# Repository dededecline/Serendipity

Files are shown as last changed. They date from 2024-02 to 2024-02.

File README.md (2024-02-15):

# Serendipity
Serendipity in silver top with "brass" DDD logo badge color. Keycap set is JTK Grìseann, a WoB set with green US-International sublegends. Background is a series of interlocking swirls and circles in dark blue, light blue, teal, and white with yellow "flower" symbols.

## Board Details
Serendipity is a collaboration between [dededecline](https://github.com/dededecline) and [liv](https://github.com/ojthetiny)

Photos by group buy participants can be found [here!](https://imgur.com/a/I6LpYkj)

More info can be found on the [Geekhack interest check.](https://geekhack.org/index.php?topic=119558)

## Hardware
* **Back Case Screws:** [4x m3x14mm](https://www.mcmaster.com/92832A566)
* **Front Case Screws:** [4x m3x8mm](https://www.mcmaster.com/90991A113)
* **Weight Screws:** [2x m3x5mm countersunk](https://www.mcmaster.com/90236A118)
* **Plate Screws:** [8x m3x8mm](https://www.mcmaster.com/90991A113)
* **Badge Screws:** [2x m2x5mm](https://www.mcmaster.com/90236A103)
* **DB Screws:** [4x m2x5mm](https://www.mcmaster.com/90236A103)
* **O-Rings:** [16x 1.5mmx2.5mm, 70 duro recommended](https://www.theoringstore.com/store/index.php?main_page=product_info&products_id=1817)
* **Feet:** [2x Geonworks 60% feet](https://geon.works/products/feet-284)

## Additional Information
The o-rings *are required* for the build to work properly. For each plate screw, one o-ring goes between the top case piece and the plate, and another goes between the plate and the screw head. Do not overly tighten plate screws.

All files required for manufacturing are present in this repository.

All relevant information about the board should be in the Geekhack interest check.

## ***DISCLAIMER***
These components have been tested and confirmed to work properly. I am not liable for any issues stemming from usage of these files. Order at your own risk. Support will not be provided, but pull requests will be reviewed and possibly accepted.

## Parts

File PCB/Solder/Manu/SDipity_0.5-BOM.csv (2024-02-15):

Comment | Designator | Footprint | LCSC
27 | R2,R3 | R_0402_1005Metric | C100353
1k | R1,R4,R5 | R_0402_1005Metric | C11702
.1u | C10,C11,C12,C13,C14,C15,C3,C5,C6,C9 | C_0402_1005Metric | C1525
10u | C7 | C_0402_1005Metric | C15525
22pF | C1,C2 | C_0402_1005Metric | C1555
RP2040 | U1 | RP2040-QFN-56 | C2040
220 | R8,R9 | R_0402_1005Metric | C25104
PRTR5V0U2X | U4 | SOT143B | C2827688
Boot | SW1,SW2 | SW_SPST_TL3342 | C318884
1u | C16,C17,C4,C8 | C_0402_1005Metric | C52923
XC6206PxxxMR | U3 | SOT-23 | C5446
SM04B | J1 | Molex_Pico-EZmate_78171-0004_1x04-1MP_P1.20mm_Vertical | C588524
D_Small | D1,D10,D11,D12,D13,D14,D15,D16,D17,D18,D19,D2,D20,D21,D22,D23,D24,D25,D26,D27,D28,D29,D3,D30,D31,D32,D33,D34,D35,D36,D37,D38,D39,D4,D40,D41,D42,D43,D44,D45,D46,D47,D48,D49,D5,D50,D51,D52,D53,D54,D55,D56,D57,D58,D59,D6,D60,D61,D62,D63,D7,D8,D9 | D_SOD-123 | C64898
12MHz | Y1 | Crystal_SMD_3225-4Pin_3.2x2.5mm | C9002
W25Q128JVS | U2 | SOIC-8_5.23x5.23mm_P1.27mm | C97521

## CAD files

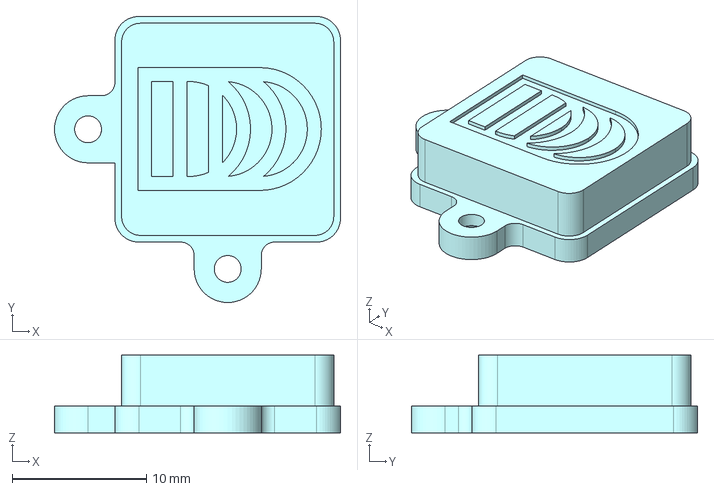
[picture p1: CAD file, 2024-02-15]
Case/Badge/Serendipity Logo Badge.step
21.3 x 21.3 x 5.80 mm

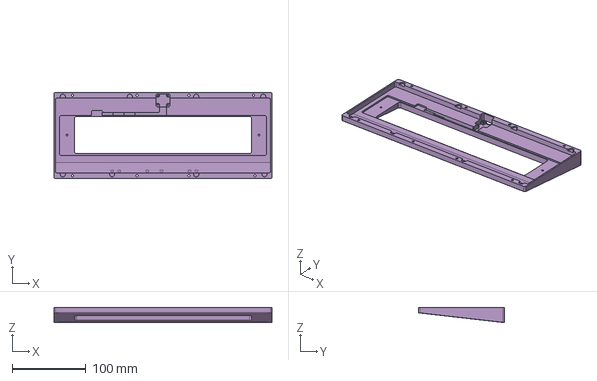
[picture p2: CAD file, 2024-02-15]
Case/Bottom/Serendipity Bottom.step
295.3 x 116.8 x 20.7 mm

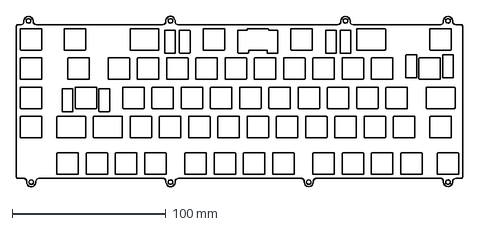
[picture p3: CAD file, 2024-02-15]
Case/Plate/Serendipity Plate.dxf
290.5 x 111.3 mm

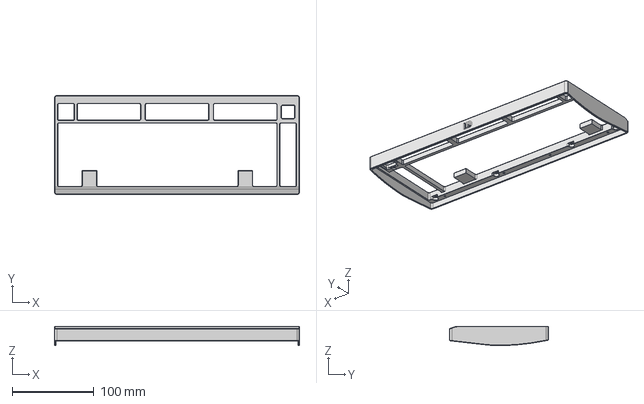
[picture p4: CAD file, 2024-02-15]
Case/Top/Serendipity WKL Top.step
299.5 x 121.0 x 23.6 mm

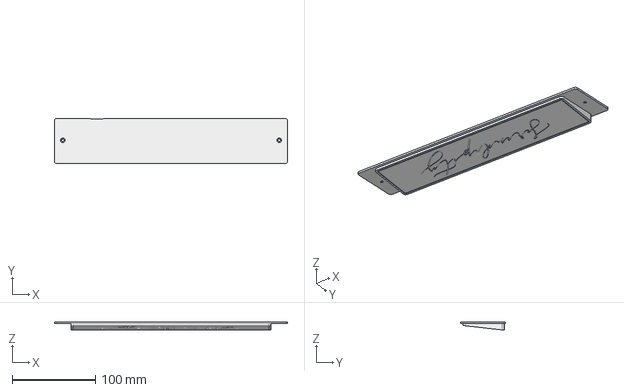
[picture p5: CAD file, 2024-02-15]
Case/Weight/Serendipity Weight.step
279.8 x 54.3 x 10.1 mm

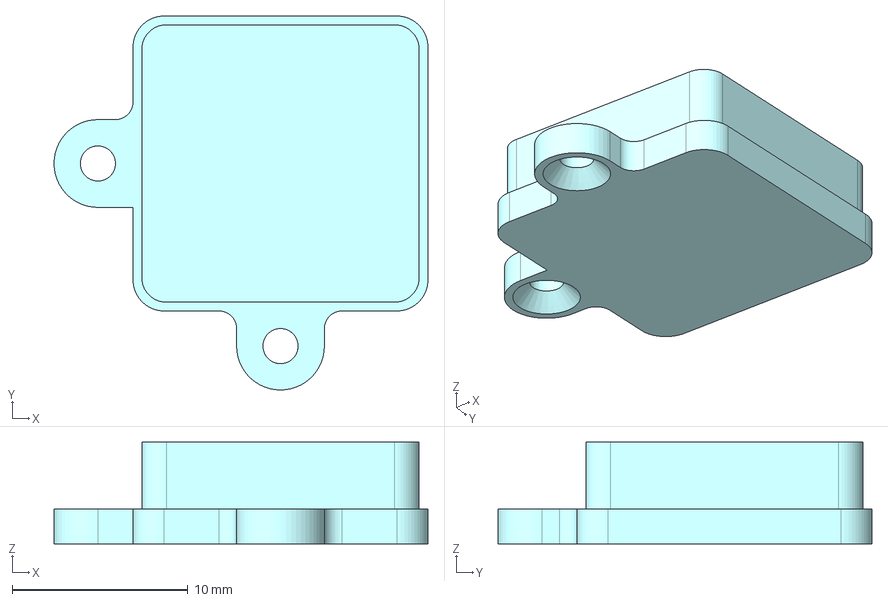
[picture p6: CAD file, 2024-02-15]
Case/Badge/Serendipity Blank Badge.step
21.3 x 21.3 x 5.80 mm

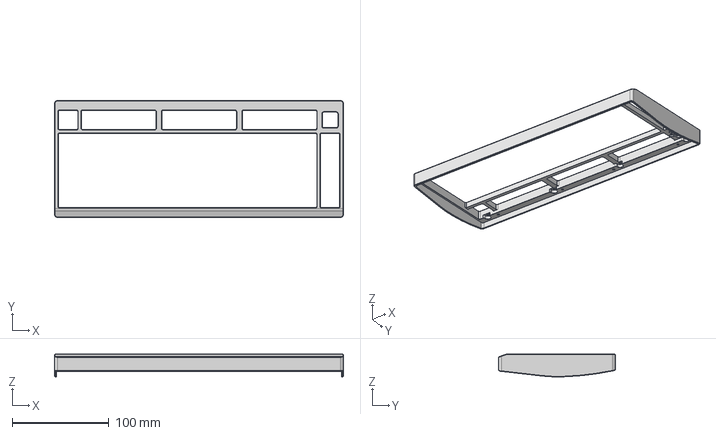
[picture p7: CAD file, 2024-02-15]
Case/Top/Serendipity WK Top.step
299.5 x 121.0 x 23.6 mm

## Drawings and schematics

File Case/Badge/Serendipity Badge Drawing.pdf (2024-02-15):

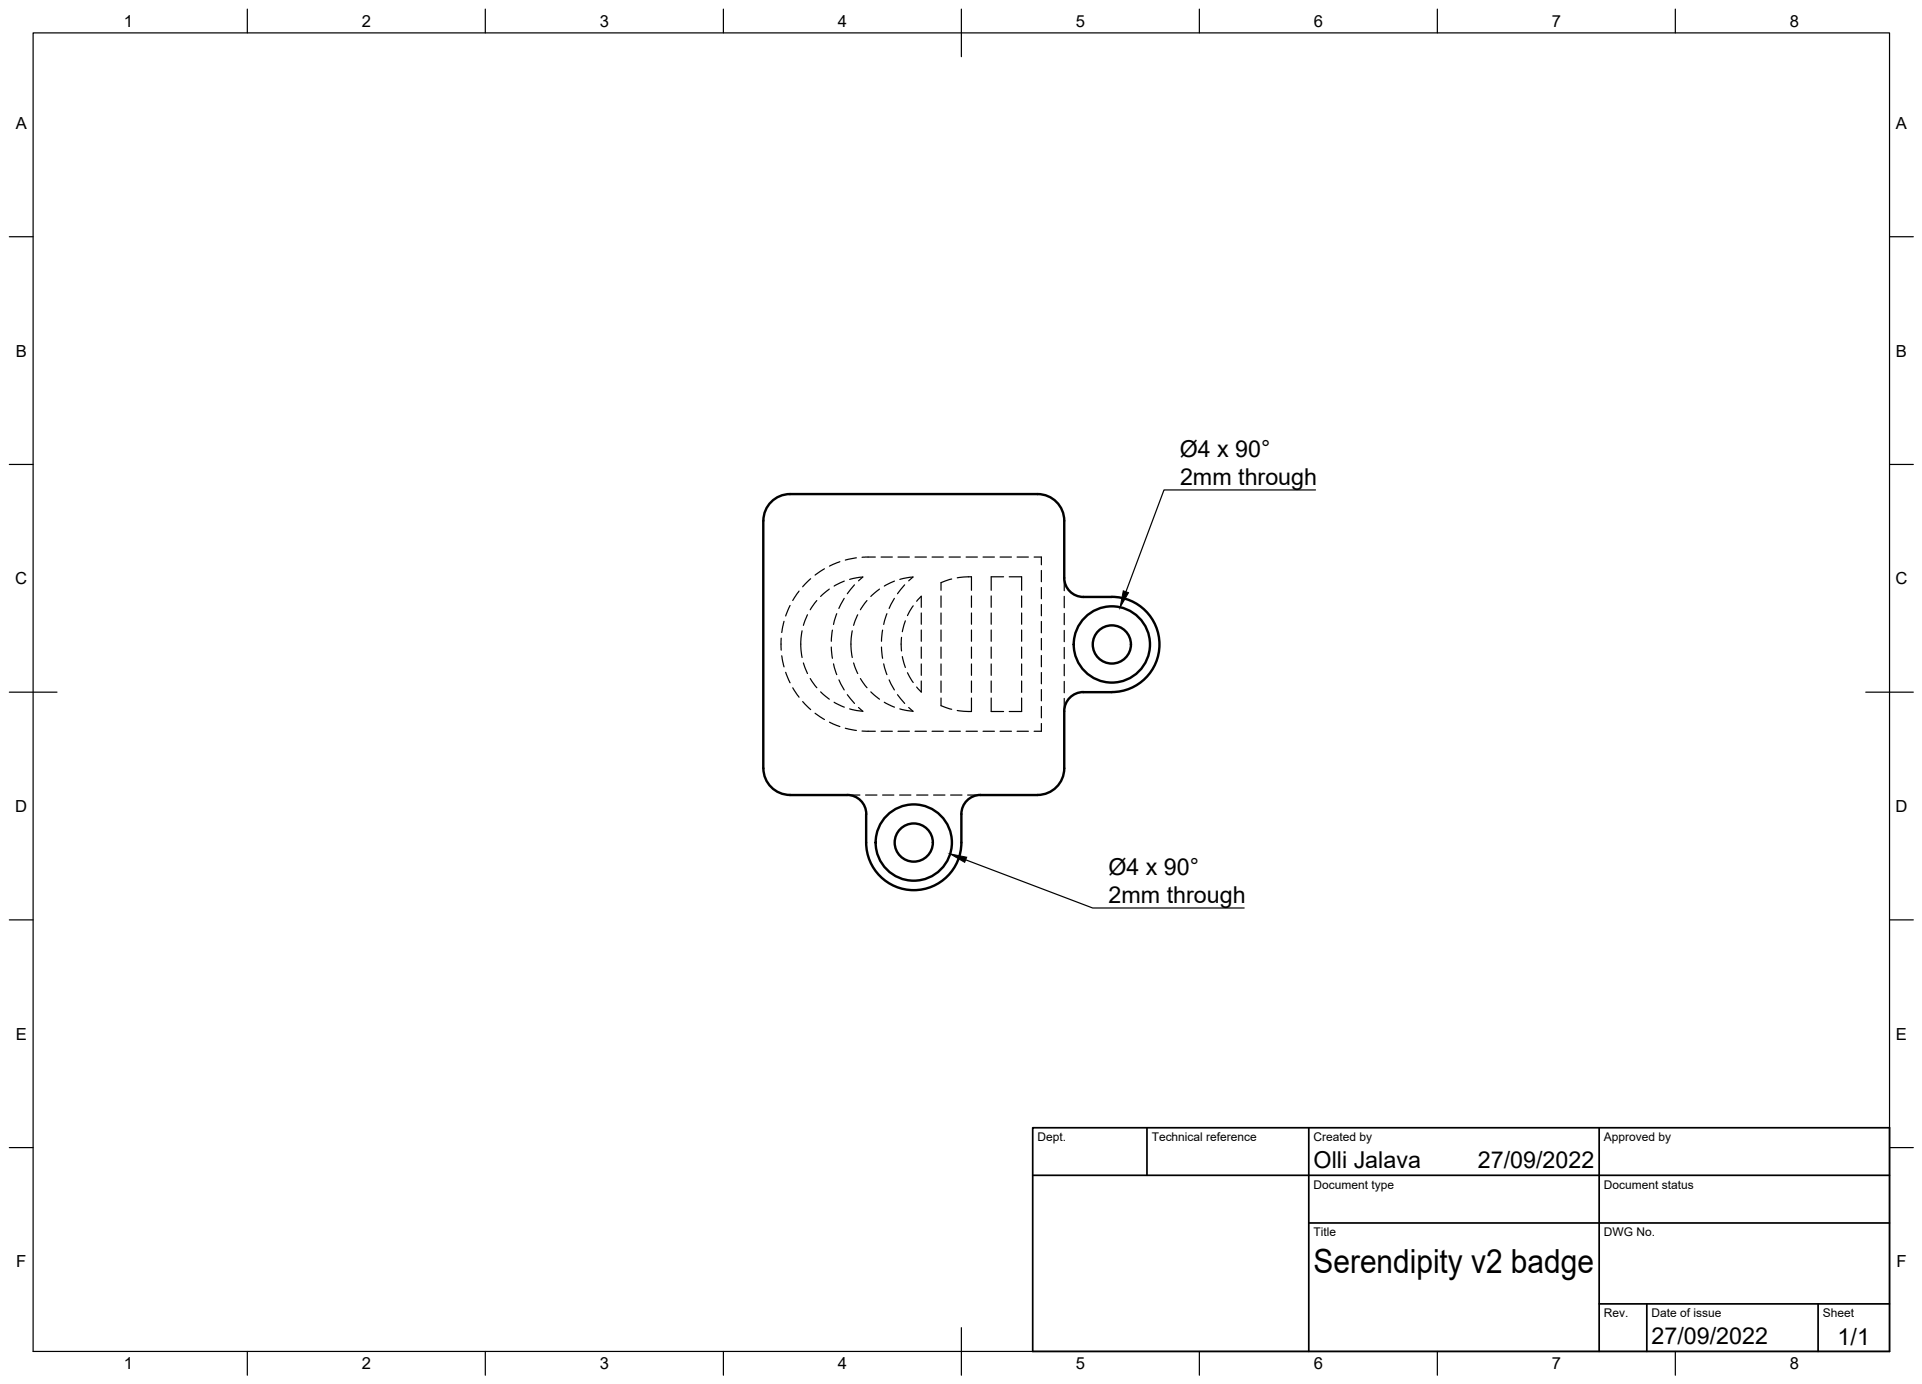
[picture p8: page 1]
Title; DWG No.; Rev.; Date of issue; Sheet; Serendipity v2 badge; Ø4 x 90° 2mm through

Dept. | Technical reference | Created by Olli Jalava 27/09/2022 | Approved by

Document type | Document status

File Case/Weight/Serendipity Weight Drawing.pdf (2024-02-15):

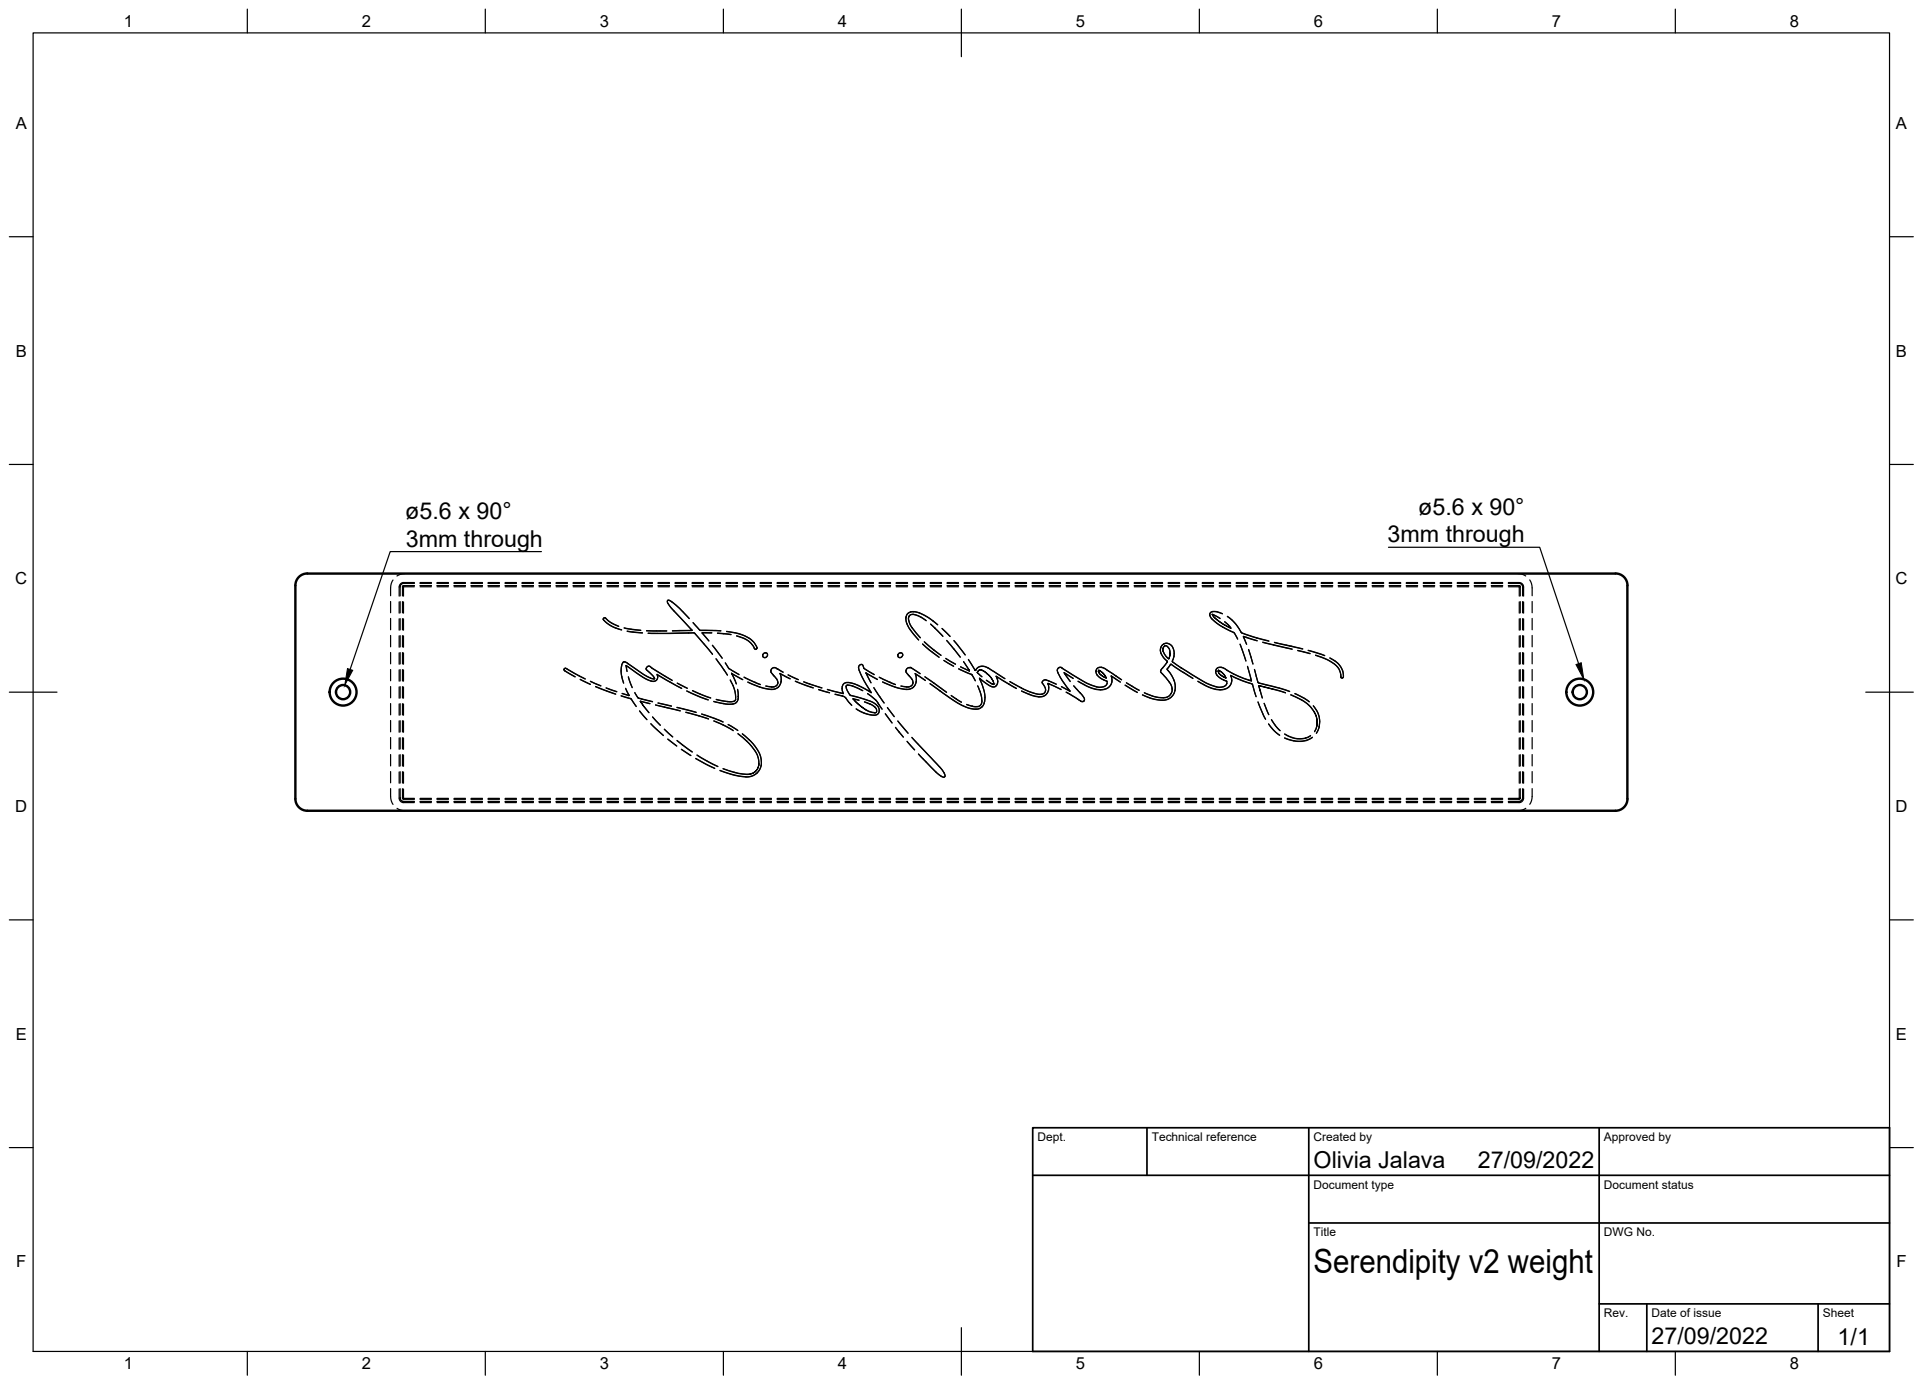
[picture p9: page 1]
Title; DWG No.; Rev.; Date of issue; Sheet; Serendipity v2 weight; ø5.6 x 90° 3mm through

Dept. | Technical reference | Created by Olivia Jalava 27/09/2022 | Approved by

Document type | Document status

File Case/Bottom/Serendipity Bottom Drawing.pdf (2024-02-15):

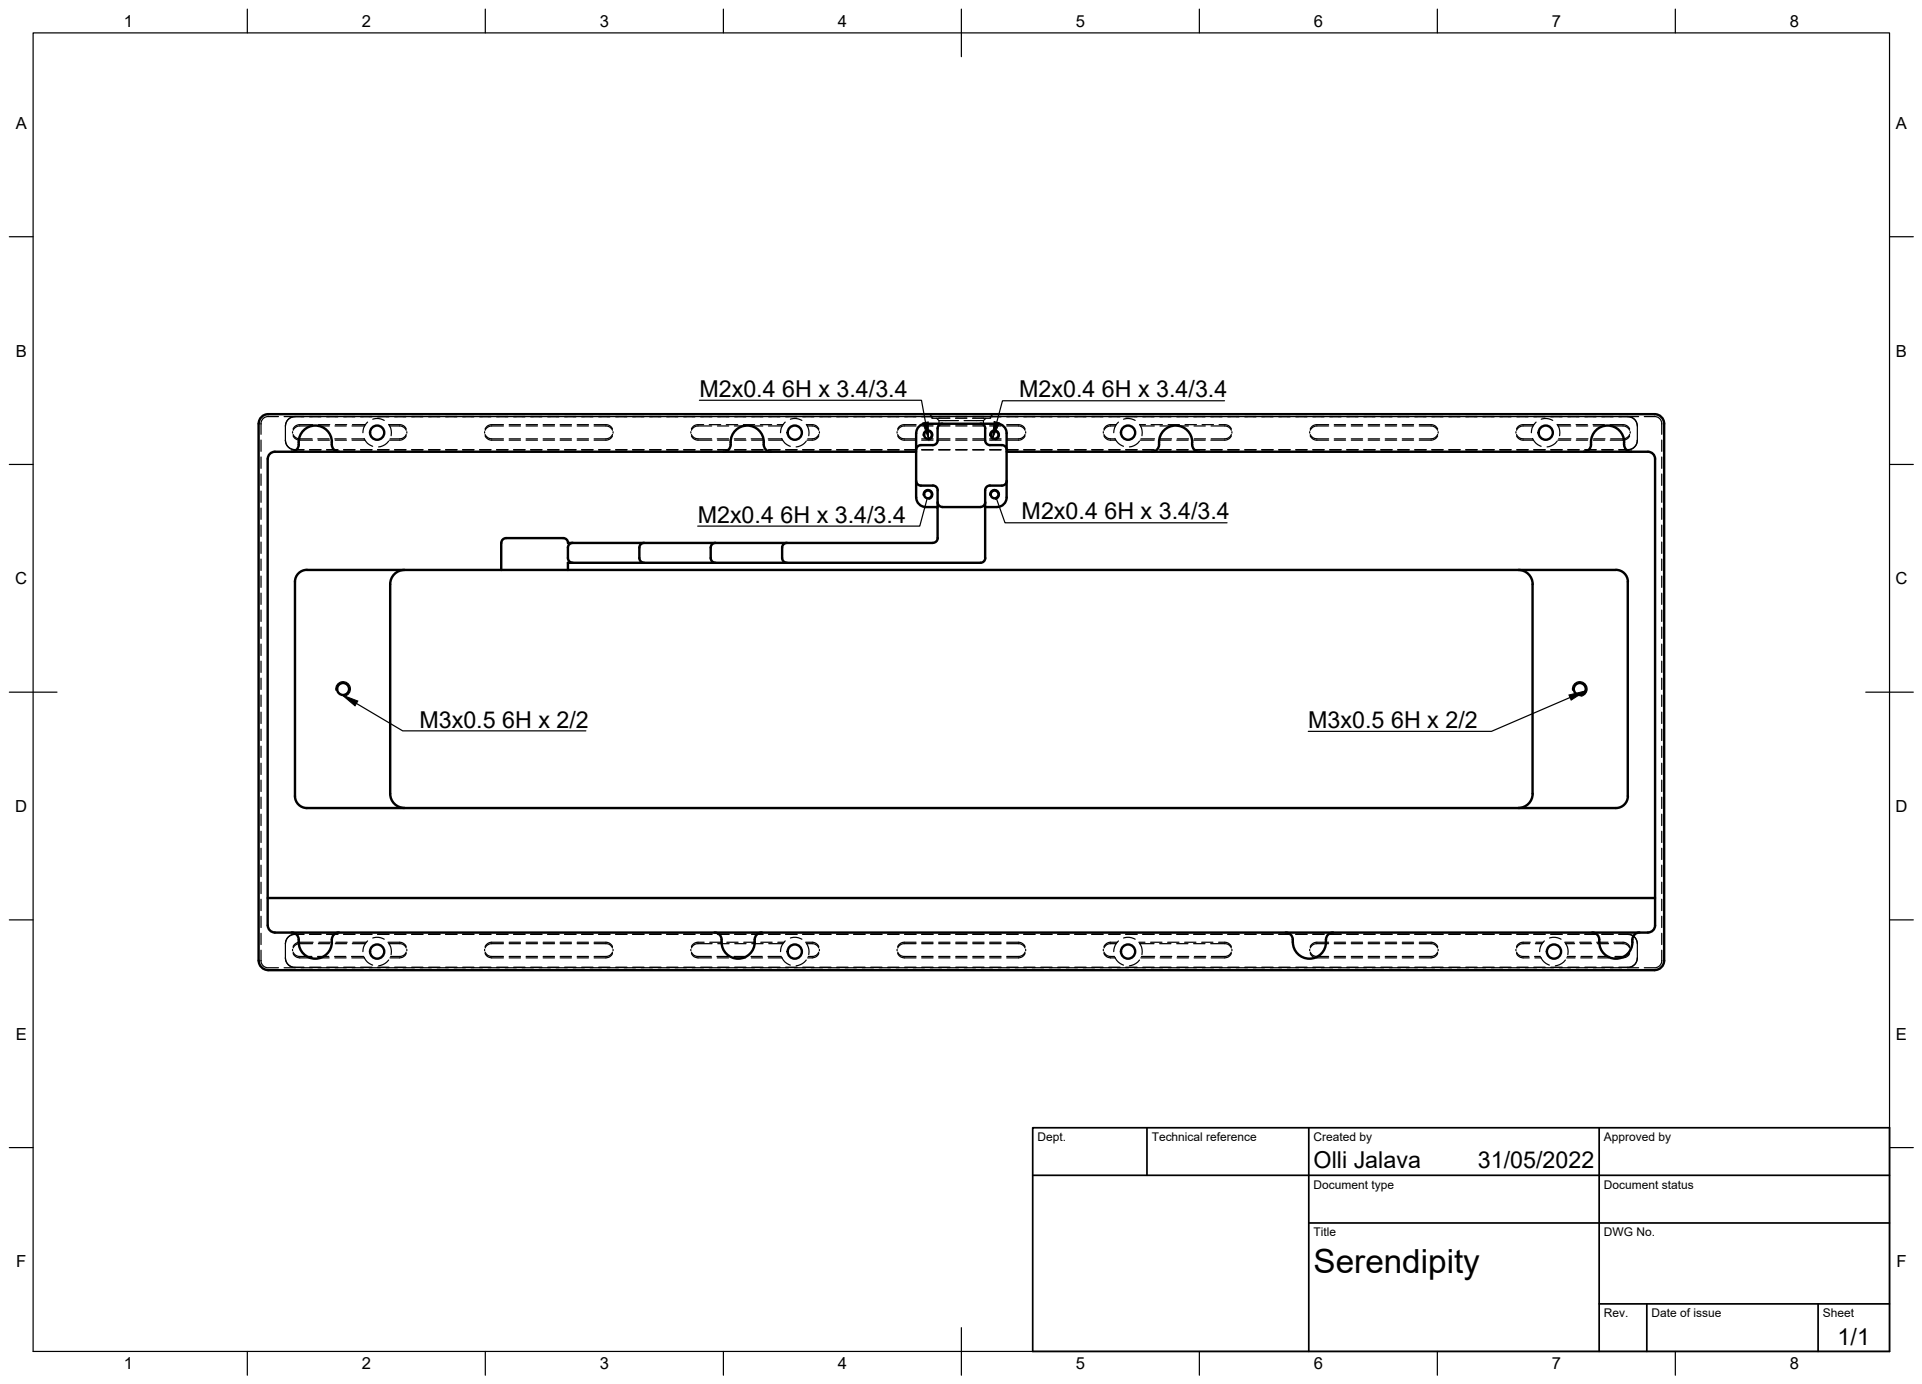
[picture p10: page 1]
Title; DWG No.; Rev.; Date of issue; Sheet

Dept. | Technical reference | Created by Olli Jalava 31/05/2022 | Approved by

Document type | Document status

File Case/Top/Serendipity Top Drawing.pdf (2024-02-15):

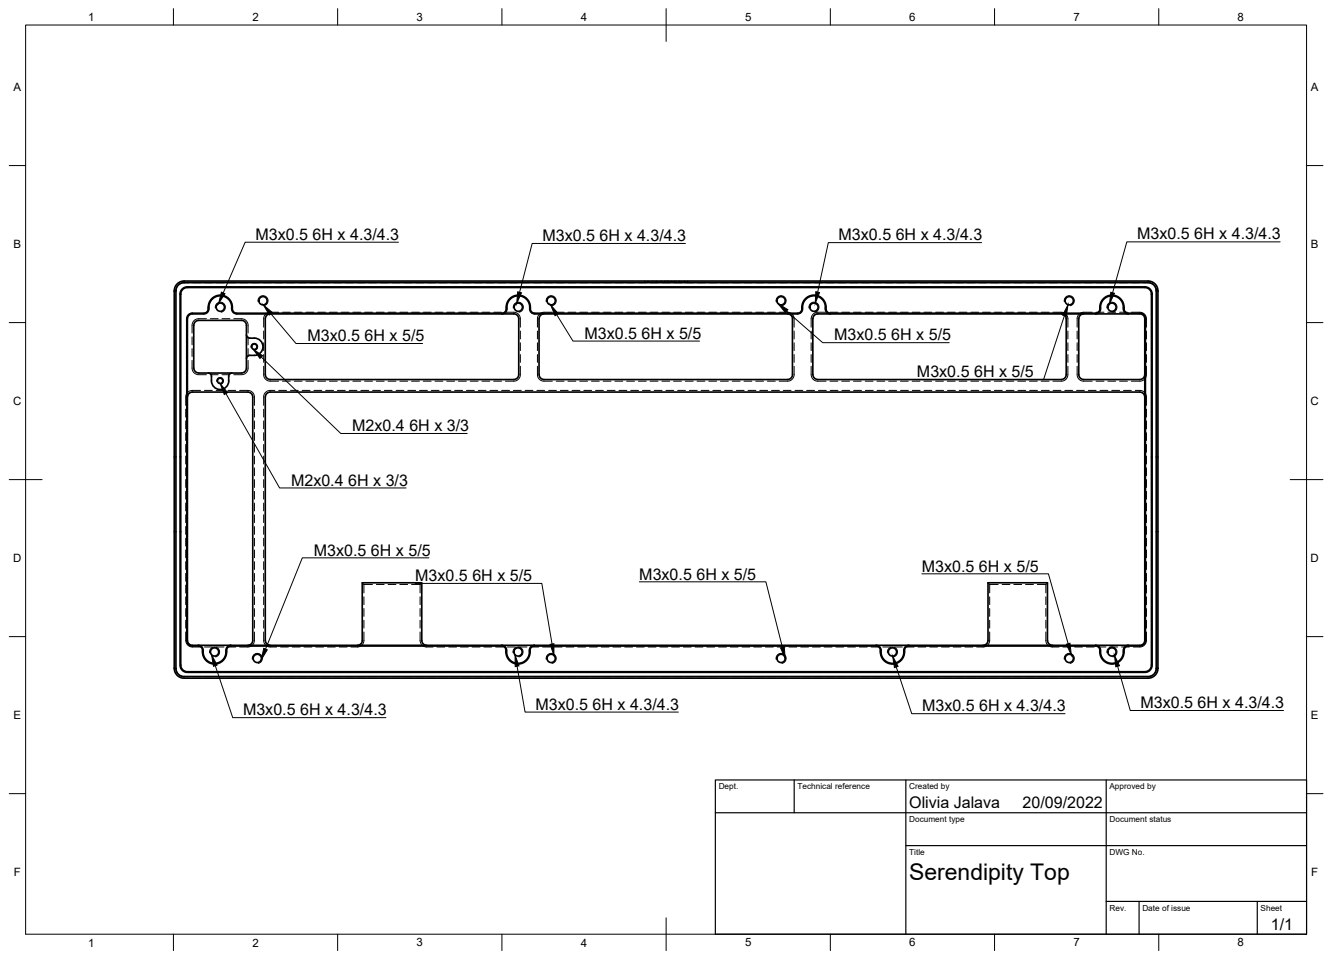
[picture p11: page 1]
Title; DWG No.; Rev.; Date of issue; Sheet; Serendipity Top

Dept. | Technical reference | Created by Olivia Jalava 20/09/2022 | Approved by

Document type | Document status

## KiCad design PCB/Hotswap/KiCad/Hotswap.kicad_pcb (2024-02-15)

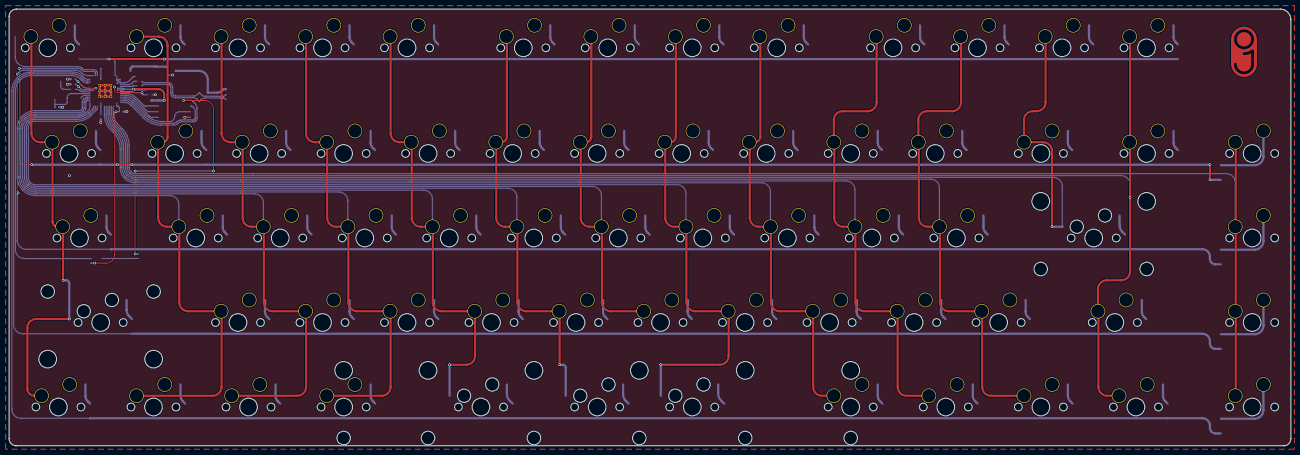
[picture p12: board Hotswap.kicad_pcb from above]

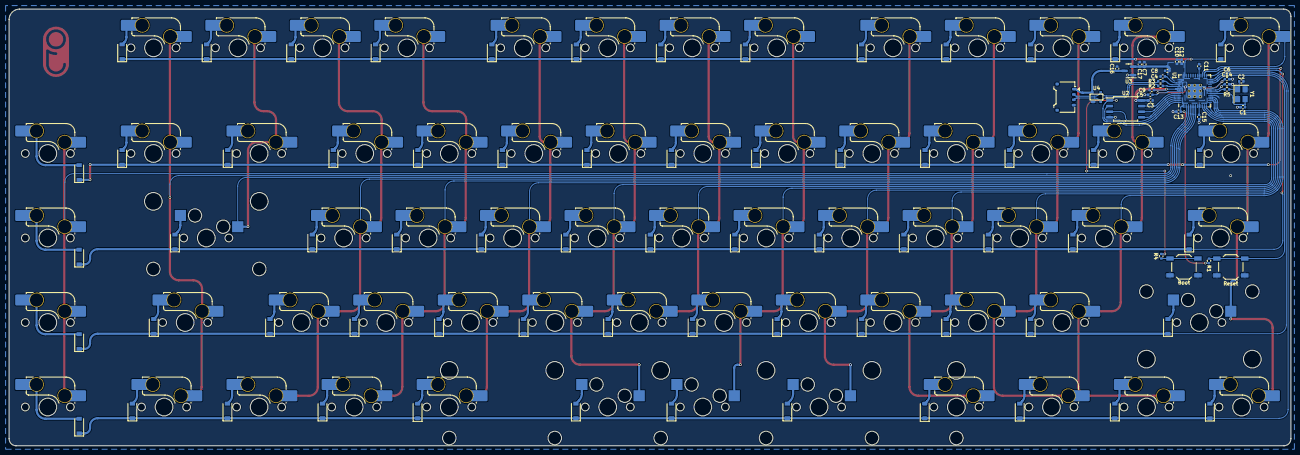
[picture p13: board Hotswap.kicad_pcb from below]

Board: 2 copper layers, 288.9 x 98.4 mm, 160 parts (155 on the bottom side), 103 nets.

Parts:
C1, C2: 22pF; C_0402_1005Metric
C3, C5, C6, C9, C10, C11, C12, C13, C14, C15: .1u; C_0402_1005Metric
C4, C8, C16, C17: 1u; C_0402_1005Metric
C7: 10u; C_0402_1005Metric
D1, D2, D3, D4, D5, D6, D7, D8, D9, D10, D11, D12, D13, D14, D15, D16, D17, D18, D19, D20, D21, D22, D23, D24, D25, D26, D27, D28, D29, D30, D31, D32, D33, D34, D35, D36, D37, D38, D39, D40, D41, D42, D43, D44, D45, D46, D47, D48, D49, D50, D51, D52, D53, D54, D55, D56, D57, D58, D59, D60, D61, D62, D63, D64, D65: D_Small; D_SOD-123
J1: EZmate; Molex_Pico-EZmate_78171-0004_1x04-1MP_P1.20mm_Vertical
MX1, MX3, MX7, MX8, MX9, MX10, MX11, MX12, MX13, MX14, MX15, MX16, MX18, MX19, MX20, MX21, MX22, MX23, MX24, MX25, MX27, MX28, MX29, MX30, MX33, MX34, MX35, MX36, MX37, MX38, MX39, MX40, MX42, MX43, MX44, MX45, MX46, MX47, MX48, MX49, MX52, MX53, MX54, MX55, MX56, MX57, MX61, MX65, MX66, MX67, MX68, MX69: MX-NoLED; SW_MX_HS_1u
MX2, MX60: MX-NoLED; SW_MX_HS_1.5u
MX4: MX-NoLED; MXOnly-2.25U-Hotswap
MX5, MX17, MX51, MX64: MX-NoLED; SW_MX_HS_1.25u
MX6, MX63: MX-NoLED; SW_MX_HS_1.75u
MX26, MX59: MX-NoLED; MXOnly-2.25U-Hotswap-ReversedStabilizers
MX31: MX-NoLED; MXOnly-7U-Hotswap-ReversedStabilizers
MX41: MX-NoLED; MXOnly-2.75U-Hotswap-ReversedStabilizers
R1, R4, R5: 1k; R_0402_1005Metric
R2, R3: 27; R_0402_1005Metric
SW1: Boot; SW_SPST_TL3342
SW2: Reset; SW_SPST_TL3342
U1: RP2040; RP2040-QFN-56
U2: W25Q128JVS; SOIC-8_5.23x5.23mm_P1.27mm
U3: XC6206PxxxMR; SOT-23
U4: PRTR5V0U2X; SOT143B
Y1: 12MHz; Crystal_SMD_3225-4Pin_3.2x2.5mm

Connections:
+1V1: C4.1, C5.1, C6.1, U1.23 (DVDD), U1.45 (VREG_VOUT), U1.50 (DVDD)
+3V3: C3.1, C7.1, C8.1, C9.1, C10.1, C11.1, C12.1, C13.1, C14.1, C15.1, C17.1, R1.1, U1.1 (IOVDD), U1.10 (IOVDD), U1.22 (IOVDD), U1.33 (IOVDD), U1.42 (IOVDD), U1.43 (ADC_AVDD), U1.44 (VREG_VIN), U1.48 (USB_VDD), U1.49 (IOVDD), U2.8 (VCC), U3.2 (VO)
+5V: C16.1, J1.1, U3.3 (VI), U4.4 (VCC)
CS: R4.2, U1.56 (QSPI_SS_N), U2.1 (~CS)
D+: J1.3, R2.1, U4.2 (IO1)
D-: J1.2, R3.1, U4.3 (IO2)
GND: C1.1, C2.1, C3.2, C4.2, C5.2, C6.2, C7.2, C8.2, C9.2, C10.2, C11.2, C12.2, C13.2, C14.2, C15.2, C16.2, C17.2, J1.4, SW1.1, SW2.2, U1.19 (TESTEN), U1.57 (GND), U2.4 (GND), U3.1 (GND), U4.1 (GND), Y1.2, Y1.4
unnamed: C2.2, R5.1, Y1.1
unnamed: D1.2 (A), MX1.2 (ROW)
unnamed: D2.2 (A), MX2.2 (ROW)
unnamed: D3.2 (A), MX4.2 (ROW)
unnamed: D4.2 (A), MX5.2 (ROW)
unnamed: D5.2 (A), MX6.2 (COL)
unnamed: D6.2 (A), MX7.2 (ROW)
unnamed: D7.2 (A), MX8.2 (ROW)
unnamed: D8.2 (A), MX9.2 (ROW)
unnamed: D9.2 (A), MX10.2 (ROW)
unnamed: D10.2 (A), MX11.2 (ROW)
unnamed: D11.2 (A), MX12.2 (ROW)
unnamed: D12.2 (A), MX13.2 (ROW)
unnamed: D13.2 (A), MX14.2 (ROW)
unnamed: D14.2 (A), MX15.2 (ROW)
unnamed: D15.2 (A), MX17.2 (COL)
unnamed: D16.2 (A), MX18.2 (ROW)
unnamed: D17.2 (A), MX19.2 (ROW)
unnamed: D18.2 (A), MX20.2 (ROW)
unnamed: D19.2 (A), MX21.2 (ROW)
unnamed: D20.2 (A), MX22.2 (ROW)
unnamed: D21.2 (A), MX23.2 (ROW)
unnamed: D22.2 (A), MX24.2 (ROW)
unnamed: D23.2 (A), MX25.2 (ROW)
unnamed: D24.2 (A), MX26.2 (ROW)
unnamed: D25.2 (A), MX27.2 (ROW)
unnamed: D26.2 (A), MX28.2 (ROW)
unnamed: D27.2 (A), MX29.2 (ROW)
unnamed: D28.2 (A), MX30.2 (ROW)
unnamed: D29.2 (A), MX31.2 (ROW)
unnamed: D30.2 (A), MX33.2 (ROW)
unnamed: D31.2 (A), MX34.2 (ROW)
unnamed: D32.2 (A), MX35.2 (ROW)
unnamed: D33.2 (A), MX36.2 (ROW)
unnamed: D34.2 (A), MX37.2 (ROW)
unnamed: D35.2 (A), MX38.2 (ROW)
unnamed: D36.2 (A), MX39.2 (ROW)
unnamed: D37.2 (A), MX40.2 (ROW)
unnamed: D38.2 (A), MX41.2 (ROW)
unnamed: D39.2 (A), MX42.2 (ROW)
unnamed: D40.2 (A), MX43.2 (ROW)
unnamed: D41.2 (A), MX44.2 (ROW)
unnamed: D42.2 (A), MX45.2 (ROW)
unnamed: D43.2 (A), MX46.2 (ROW)
unnamed: D44.2 (A), MX47.2 (ROW)
unnamed: D45.2 (A), MX48.2 (ROW)
unnamed: D46.2 (A), MX49.2 (ROW)
unnamed: D47.2 (A), MX51.2 (COL)
unnamed: D48.2 (A), MX52.2 (ROW)
unnamed: D49.2 (A), MX53.2 (ROW)
unnamed: D50.2 (A), MX54.2 (ROW)
unnamed: D51.2 (A), MX55.2 (ROW)
unnamed: D52.2 (A), MX56.2 (ROW)
unnamed: D53.2 (A), MX57.2 (ROW)
unnamed: D54.2 (A), MX59.2 (ROW)
unnamed: D55.2 (A), MX60.2 (COL)
unnamed: D56.2 (A), MX61.2 (ROW)
unnamed: D57.2 (A), MX63.2 (ROW)
unnamed: D58.2 (A), MX64.2 (ROW)
unnamed: D59.2 (A), MX65.2 (COL)
unnamed: D60.2 (A), MX66.2 (ROW)
unnamed: D61.2 (A), MX67.2 (ROW)
unnamed: D62.2 (A), MX68.2 (ROW)
unnamed: D63.2 (A), MX69.2 (ROW)
unnamed: D64.2 (A), MX3.2 (ROW)
unnamed: D65.2 (A), MX16.2 (COL)
unnamed: R4.1, SW1.2
unnamed: R2.2, U1.47 (D+)
unnamed: R3.2, U1.46 (D-)
QSPI_CLK: U1.52 (QSPI_SCLK), U2.6 (CLK)
RESET: R1.2, SW2.1, U1.26 (~RUN)
SD0: U1.53 (QSPI_SD0), U2.5 (DI(IO0))
SD1: U1.55 (QSPI_SD1), U2.2 (DO(IO1))
SD2: U1.54 (QSPI_SD2), U2.3 (IO2)
SD3: U1.51 (QSPI_SD3), U2.7 (IO3)
XTAL_IN: C1.2, U1.20 (XTAL_IN), Y1.3
XTAL_OUT: R5.2, U1.21 (XTAL_OUT)
col0: MX1.1 (COL), MX2.1 (COL), MX4.1 (COL), MX5.1 (COL), MX6.1 (ROW), U1.31 (GPIO20)
col1: MX7.1 (COL), MX8.1 (COL), MX9.1 (COL), MX10.1 (COL), MX11.1 (COL), U1.18 (GPIO15)
col2: MX12.1 (COL), MX13.1 (COL), MX14.1 (COL), MX15.1 (COL), MX17.1 (ROW), U1.17 (GPIO14)
col3: MX3.1 (COL), MX18.1 (COL), MX19.1 (COL), MX20.1 (COL), MX21.1 (COL), U1.16 (GPIO13)
col4: MX22.1 (COL), MX23.1 (COL), MX24.1 (COL), MX25.1 (COL), MX26.1 (COL), U1.15 (GPIO12)
col5: MX27.1 (COL), MX28.1 (COL), MX29.1 (COL), MX30.1 (COL), MX31.1 (COL), U1.14 (GPIO11)
col6: MX33.1 (COL), MX34.1 (COL), MX35.1 (COL), MX36.1 (COL), U1.13 (GPIO10)
col7: MX37.1 (COL), MX38.1 (COL), MX39.1 (COL), MX40.1 (COL), MX41.1 (COL), U1.12 (GPIO9)
col8: MX16.1 (ROW), MX42.1 (COL), MX43.1 (COL), MX44.1 (COL), MX45.1 (COL), U1.8 (GPIO6)
col9: MX46.1 (COL), MX47.1 (COL), MX48.1 (COL), MX49.1 (COL), MX51.1 (ROW), U1.7 (GPIO5)
col10: MX52.1 (COL), MX53.1 (COL), MX54.1 (COL), MX55.1 (COL), MX56.1 (COL), U1.6 (GPIO4)
col11: MX57.1 (COL), MX59.1 (COL), MX60.1 (ROW), U1.5 (GPIO3)
col12: MX61.1 (COL), MX63.1 (COL), MX64.1 (COL), MX65.1 (ROW), U1.4 (GPIO2)
col13: MX66.1 (COL), MX67.1 (COL), MX68.1 (COL), MX69.1 (COL), U1.3 (GPIO1)
row0: D1.1 (K), D6.1 (K), D11.1 (K), D16.1 (K), D20.1 (K), D25.1 (K), D30.1 (K), D34.1 (K), D39.1 (K), D43.1 (K), D48.1 (K), D53.1 (K), D56.1 (K), U1.41 (GPIO29/ADC3)
row1: D2.1 (K), D7.1 (K), D12.1 (K), D17.1 (K), D21.1 (K), D26.1 (K), D31.1 (K), D35.1 (K), D40.1 (K), D44.1 (K), D49.1 (K), D55.1 (K), D59.1 (K), D60.1 (K), U1.30 (GPIO19)
row2: D5.1 (K), D8.1 (K), D13.1 (K), D18.1 (K), D22.1 (K), D27.1 (K), D32.1 (K), D36.1 (K), D41.1 (K), D45.1 (K), D50.1 (K), D54.1 (K), D61.1 (K), U1.29 (GPIO18)
row3: D3.1 (K), D9.1 (K), D14.1 (K), D19.1 (K), D23.1 (K), D28.1 (K), D33.1 (K), D37.1 (K), D42.1 (K), D46.1 (K), D51.1 (K), D57.1 (K), D62.1 (K), U1.27 (GPIO16)
row4: D4.1 (K), D10.1 (K), D15.1 (K), D24.1 (K), D29.1 (K), D38.1 (K), D47.1 (K), D52.1 (K), D58.1 (K), D63.1 (K), D64.1 (K), D65.1 (K), U1.28 (GPIO17)
